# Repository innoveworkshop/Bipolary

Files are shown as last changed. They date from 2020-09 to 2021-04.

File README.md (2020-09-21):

# Bipolary

A minimalist discrete desktop class-A headphone amplifier.

## Follow Along

If you want to learn more about this project and also follow along its journey,
check out the [project's YouTube playlist](https://www.youtube.com/playlist?list=PLbjMhZ3Qv6a8xDwKZuQG69gMUy-2NGEBN).

## Component Library

In order to keep my projects 100% consistent I've built my own Eagle library,
which is all standardized and nice. So if you want to hack on this project be
sure to download the [Innove Workshop Eagle library](https://github.com/innoveworkshop/InnoveWorkshop-Eagle-Library).

## License

<br />This work is licensed under a <a rel="license" href="http://creativecommons.org/licenses/by-nc-sa/4.0/">Creative Commons Attribution-NonCommercial-ShareAlike 4.0 International License</a>.

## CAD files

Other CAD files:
CAD/Top Plate.dwg
CAD/Enclosure.dwg
CAD/Base Plate.dwg
CAD/Side Plates.dwg

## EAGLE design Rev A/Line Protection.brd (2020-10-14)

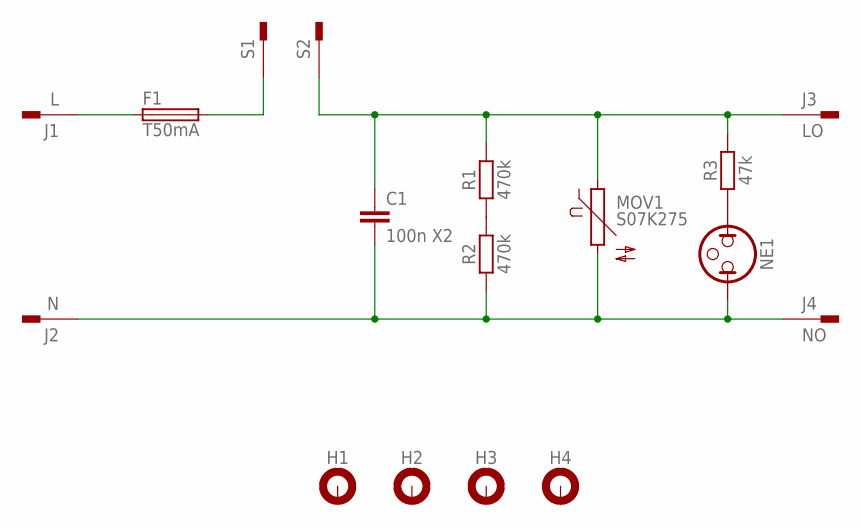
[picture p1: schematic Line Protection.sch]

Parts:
C1: 100n X2; C150-054X183
F1: T50mA; CFH14
H1, H2, H3, H4: MOUNT-PAD-ROUND3.0; 3,0-PAD
J1: L; F061.100
J2: N; F061.100
J3: LO; F061.100
J4: NO; F061.100
MOV1: S07K275
NE1: NEON-T2
R1, R2: 470k; 0207/10
R3: 47k; 0207/10
S1, S2: FASTON-250D140; F061.100

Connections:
unnamed: F1.1, J1.A1, J1.A2
unnamed: R1.1, R2.2
unnamed: NE1.1, R3.1
unnamed: F1.2, S1.A1, S1.A2
NEUTRAL: C1.2, J2.A1, J2.A2, J4.A1, J4.A2, MOV1.2, NE1.2, R2.1
SLIVE: C1.1, J3.A1, J3.A2, MOV1.1, R1.2, R3.2, S2.A1, S2.A2

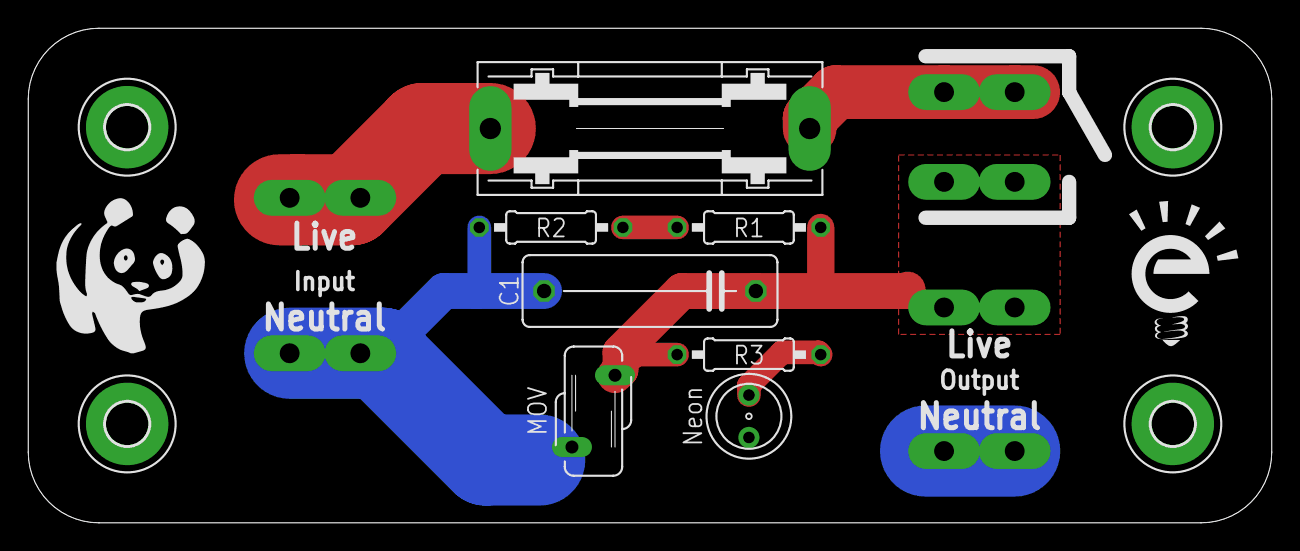
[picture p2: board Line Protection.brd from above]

Board: 2 copper layers, 88.0 x 35.0 mm, 17 parts (0 on the bottom side), 6 nets.

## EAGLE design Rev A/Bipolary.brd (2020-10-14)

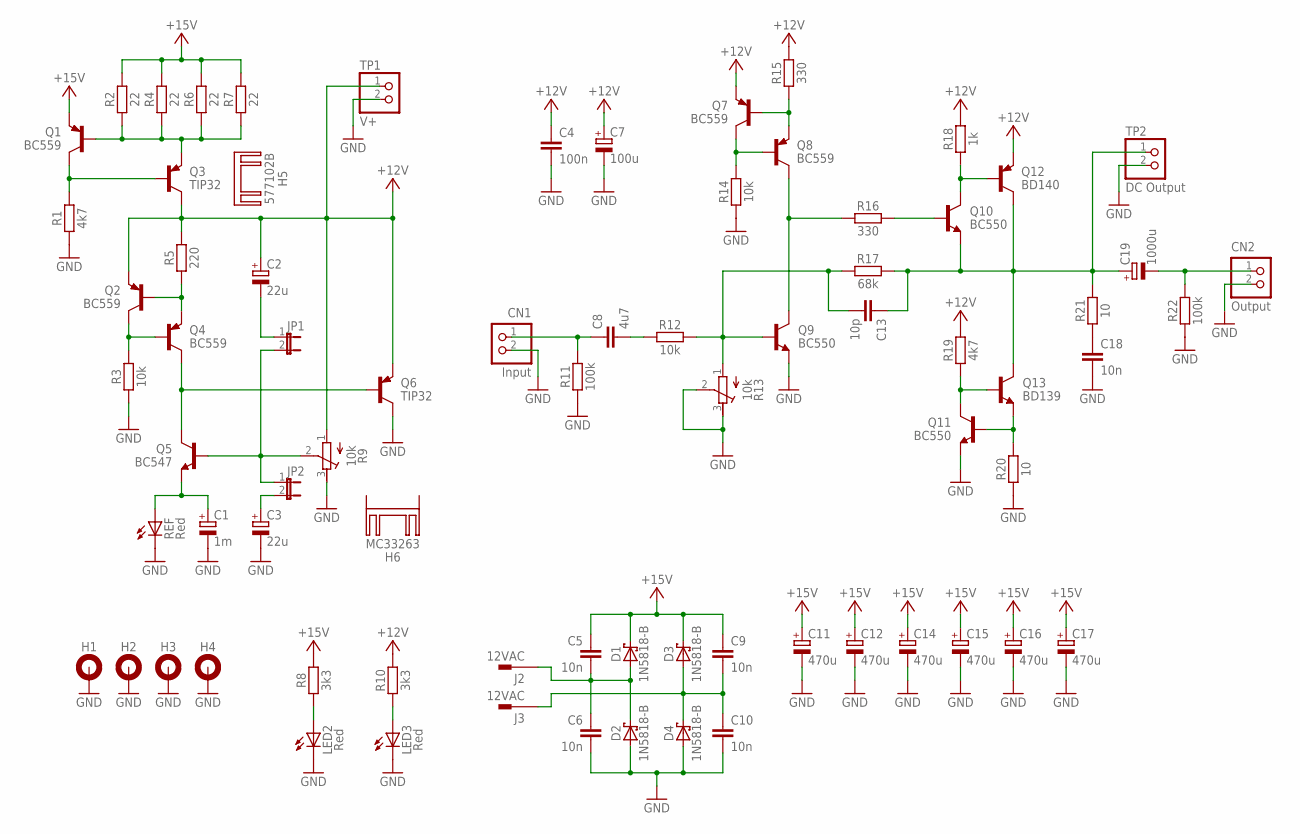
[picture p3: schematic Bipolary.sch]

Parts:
C1: 1m; E3,5-8
C2, C3: 22u; E2-5
C4: 100n; C050-025X075
C5, C6, C9, C10, C18: 10n; C050-025X075
C7: 100u; E3,5-8
C8: 4u7; C150-084X183
C11, C12, C14, C15, C16, C17: 470u; E5-10
C13: 10p; C050-025X075
C19: 1000u; E5-10
CN1: Input; B2B-XH-A
CN2: Output; B2B-XH-A
D1, D2, D3, D4: 1N5818-B; DO41-7.6
H1, H2, H3, H4: MOUNT-PAD-ROUND3.0; 3,0-PAD
H5: 577102B; D02S
H6: MC33263; SK104-PAD
J2, J3: 12VAC; F061.100
JP1, JP2: JP1E; JP1
LED2, LED3: Red; LED5MM
Q1, Q2, Q4, Q7, Q8: BC559; TO92
Q3, Q6: TIP32; TO220V
Q5: BC547; TO92
Q9, Q10, Q11: BC550; TO92
Q12: BD140; TO126V
Q13: BD139; TO126V
R1, R19: 4k7; 0207/10
R2, R4, R6, R7: 22; 0207/10
R3, R12, R14: 10k; 0207/10
R5: 220; 0207/10
R8, R10: 3k3; 0207/10
R9, R13: 10k; RTRIM3296Y
R11, R22: 100k; 0207/10
R15, R16: 330; 0207/10
R17: 68k; 0207/10
R18: 1k; 0207/10
R20, R21: 10; 0207/10
REF: Red; LED5MM
TP1: V+; 1X02
TP2: DC Output; 1X02

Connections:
+12V: C2.+, C4.1, C7.+, Q2.3 (E), Q3.2 (C), Q6.3 (E), Q7.3 (E), Q12.1 (E), R5.2, R9.1 (A), R10.2, R15.2, R18.2, R19.2, TP1.1
+15V: C5.1, C9.1, C11.+, C12.+, C14.+, C15.+, C16.+, C17.+, D1.C, D3.C, Q1.3 (E), R2.2, R4.2, R6.2, R7.2, R8.2
DCOUTPUT: C13.1, C19.+, Q10.3 (E), Q12.2 (C), Q13.2 (C), R17.2, R21.2, TP2.1
GND: C1.-, C3.-, C4.2, C6.2, C7.-, C10.2, C11.-, C12.-, C14.-, C15.-, C16.-, C17.-, C18.2, CN1.2, CN2.2, D2.A, D4.A, H1.B3,0, H2.B3,0, H3.B3,0, H4.B3,0, LED2.K (C), LED3.K (C), Q6.2 (C), Q9.3 (E), Q11.3 (E), R1.1, R3.1, R9.3 (E), R11.1, R13.2 (S), R13.3 (E), R14.1, R20.1, R22.1, REF.K (C), TP1.2, TP2.2
INPUT: C8.1, CN1.1, R11.2
INTSTAGE: Q8.1 (C), Q9.1 (C), R16.1
unnamed: Q1.1 (C), Q3.1 (B), R1.2
unnamed: C8.2, R12.1
unnamed: C5.2, C6.1, D1.A, D2.C, J2.A1, J2.A2
unnamed: Q7.1 (C), Q8.2 (B), R14.2
unnamed: Q7.2 (B), Q8.3 (E), R15.1
unnamed: Q10.1 (C), Q12.3 (B), R18.1
unnamed: Q10.2 (B), R16.2
unnamed: Q11.1 (C), Q13.3 (B), R19.1
unnamed: Q11.2 (B), Q13.1 (E), R20.2
unnamed: C18.1, R21.1
unnamed: Q1.2 (B), Q3.3 (E), R2.1, R4.1, R6.1, R7.1
unnamed: Q2.2 (B), Q4.3 (E), R5.1
unnamed: Q2.1 (C), Q4.2 (B), R3.2
unnamed: Q4.1 (C), Q5.1 (C), Q6.1 (B)
unnamed: C1.+, Q5.3 (E), REF.A
unnamed: JP1.2, JP2.1, Q5.2 (B), R9.2 (S)
unnamed: C2.-, JP1.1
unnamed: C3.+, JP2.2
unnamed: C9.2, C10.1, D3.A, D4.C, J3.A1, J3.A2
unnamed: LED3.A, R10.1
unnamed: LED2.A, R8.1
NFB: C13.2, Q9.2 (B), R12.2, R13.1 (A), R17.1
OUTPUT: C19.-, CN2.1, R22.2

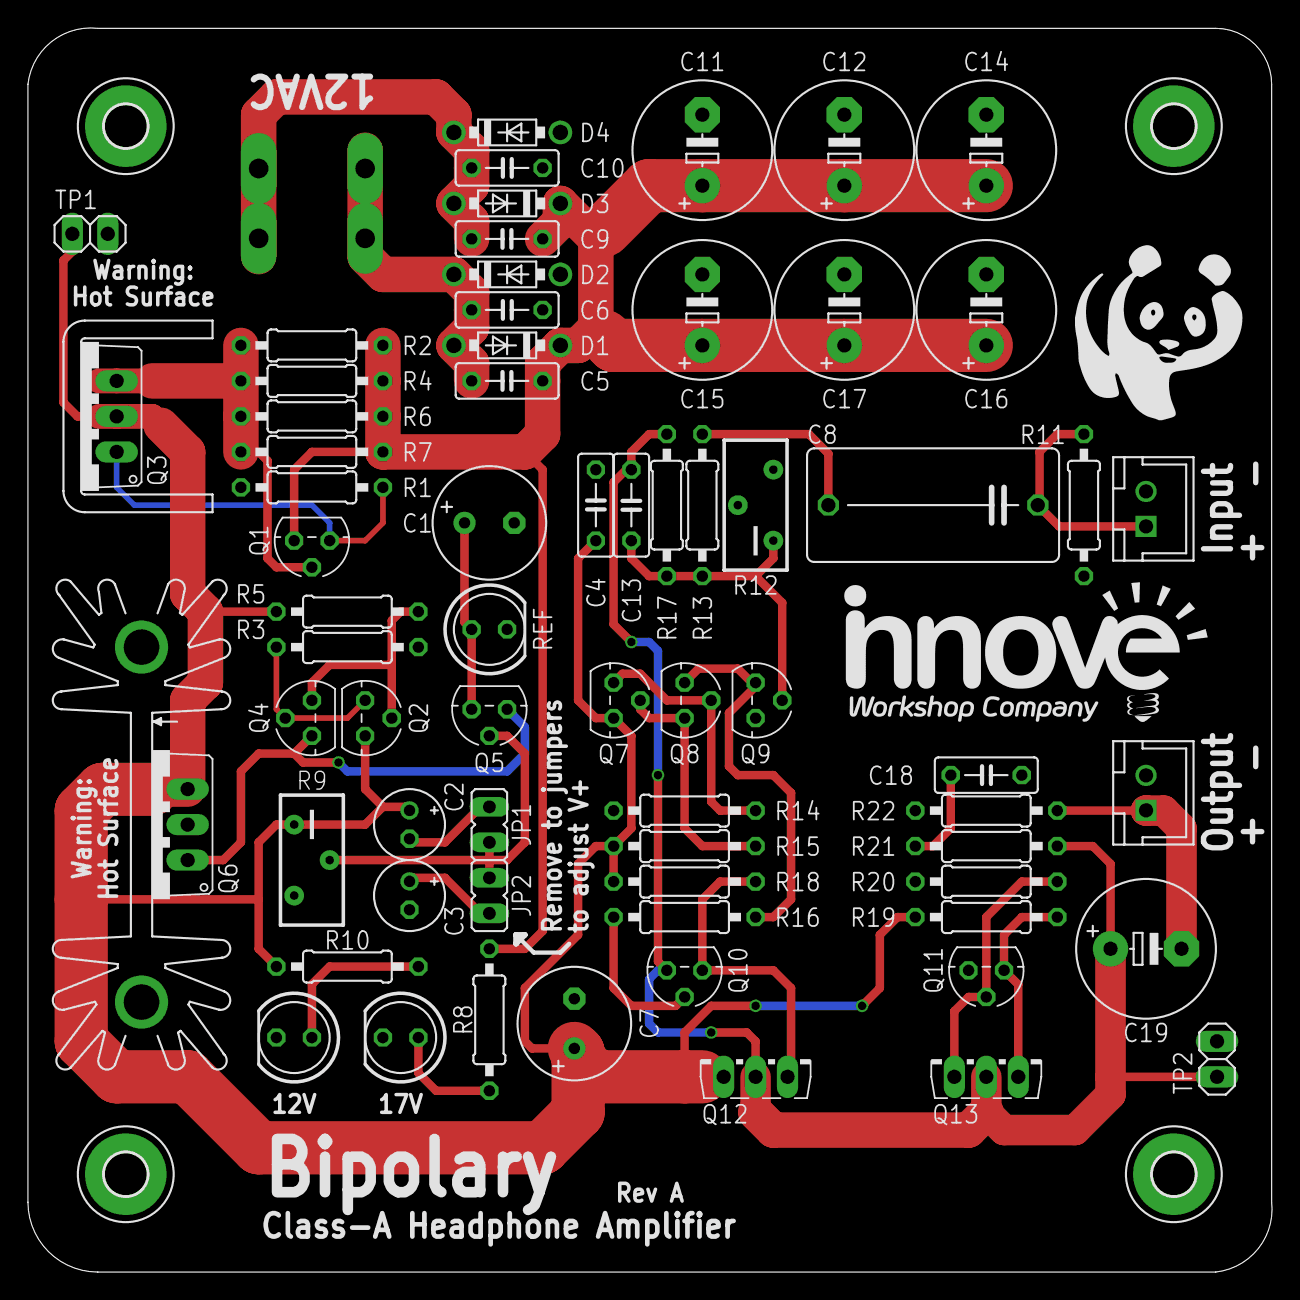
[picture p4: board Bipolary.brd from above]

Board: 2 copper layers, 89.0 x 89.0 mm, 75 parts (0 on the bottom side), 29 nets.

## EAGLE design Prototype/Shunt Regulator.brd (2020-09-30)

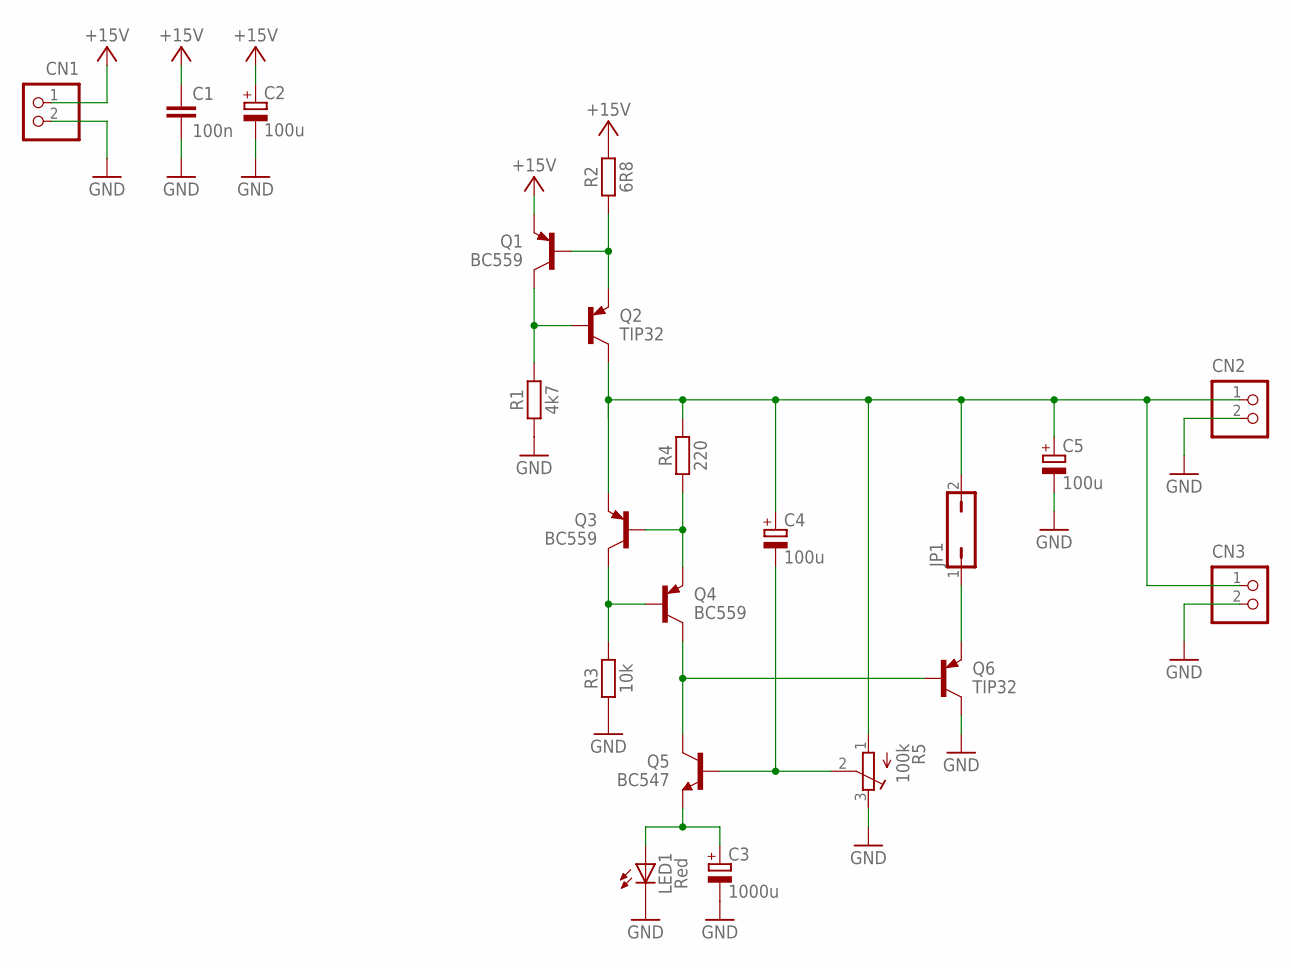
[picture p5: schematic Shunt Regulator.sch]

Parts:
C1: 100n; C050-025X075
C2, C4, C5: 100u; E2,5-6
C3: 1000u; E5-10
CN1, CN2, CN3: B2B-XH-A
JP1: JP1Q; JP1
LED1: Red; LED5MM
Q1, Q3, Q4: BC559; TO92
Q2, Q6: TIP32; TO220V
Q5: BC547; TO92
R1: 4k7; 0207/10
R2: 6R8; 0207/10
R3: 10k; 0207/10
R4: 220; 0207/10
R5: 100k; RTRIM3296Y

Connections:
+15V: C1.1, C2.+, CN1.1, Q1.3 (E), R2.2
GND: C1.2, C2.-, C3.-, C5.-, CN1.2, CN2.2, CN3.2, LED1.K (C), Q6.2 (C), R1.1, R3.1, R5.3 (E)
unnamed: Q1.1 (C), Q2.1 (B), R1.2
unnamed: Q1.2 (B), Q2.3 (E), R2.1
unnamed: Q4.1 (C), Q5.1 (C), Q6.1 (B)
unnamed: Q3.2 (B), Q4.3 (E), R4.1
unnamed: Q3.1 (C), Q4.2 (B), R3.2
unnamed: C3.+, LED1.A, Q5.3 (E)
unnamed: C4.-, Q5.2 (B), R5.2 (S)
unnamed: JP1.1, Q6.3 (E)
OUTPUT: C4.+, C5.+, CN2.1, CN3.1, JP1.2, Q2.2 (C), Q3.3 (E), R4.2, R5.1 (A)

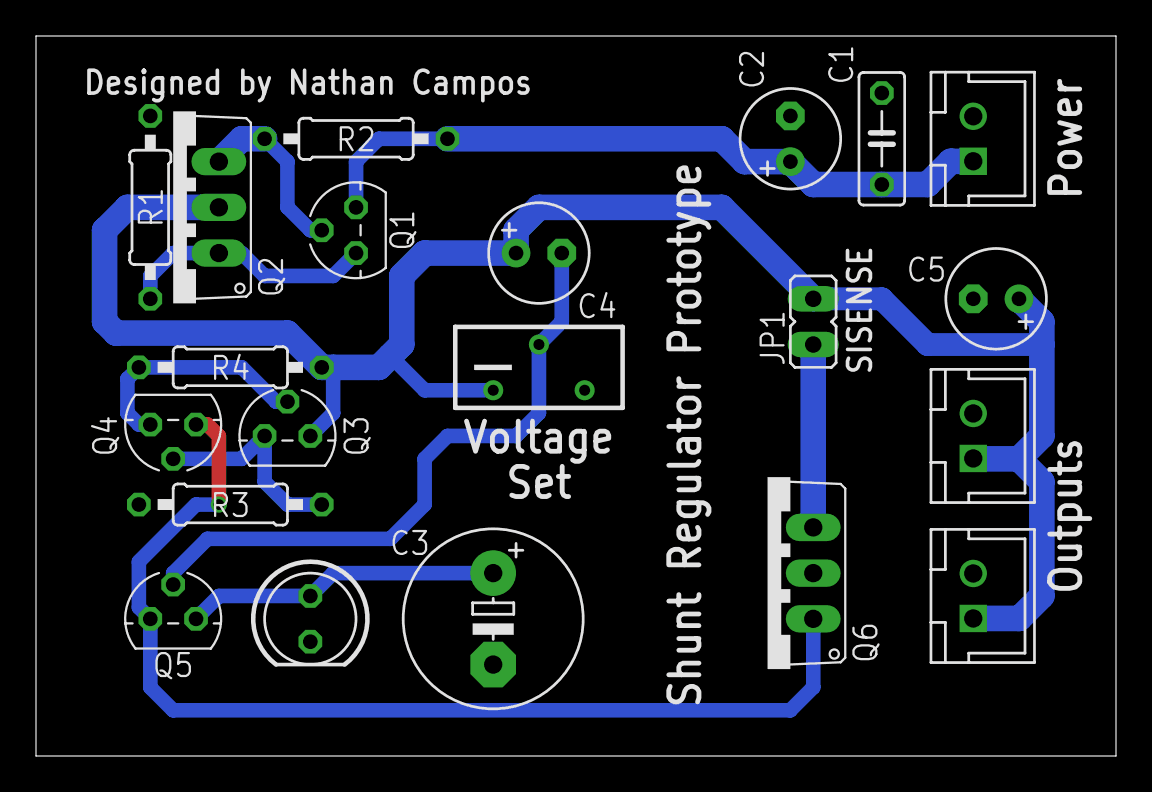
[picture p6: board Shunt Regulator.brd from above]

Board: 2 copper layers, 60.0 x 40.0 mm, 21 parts (0 on the bottom side), 11 nets.

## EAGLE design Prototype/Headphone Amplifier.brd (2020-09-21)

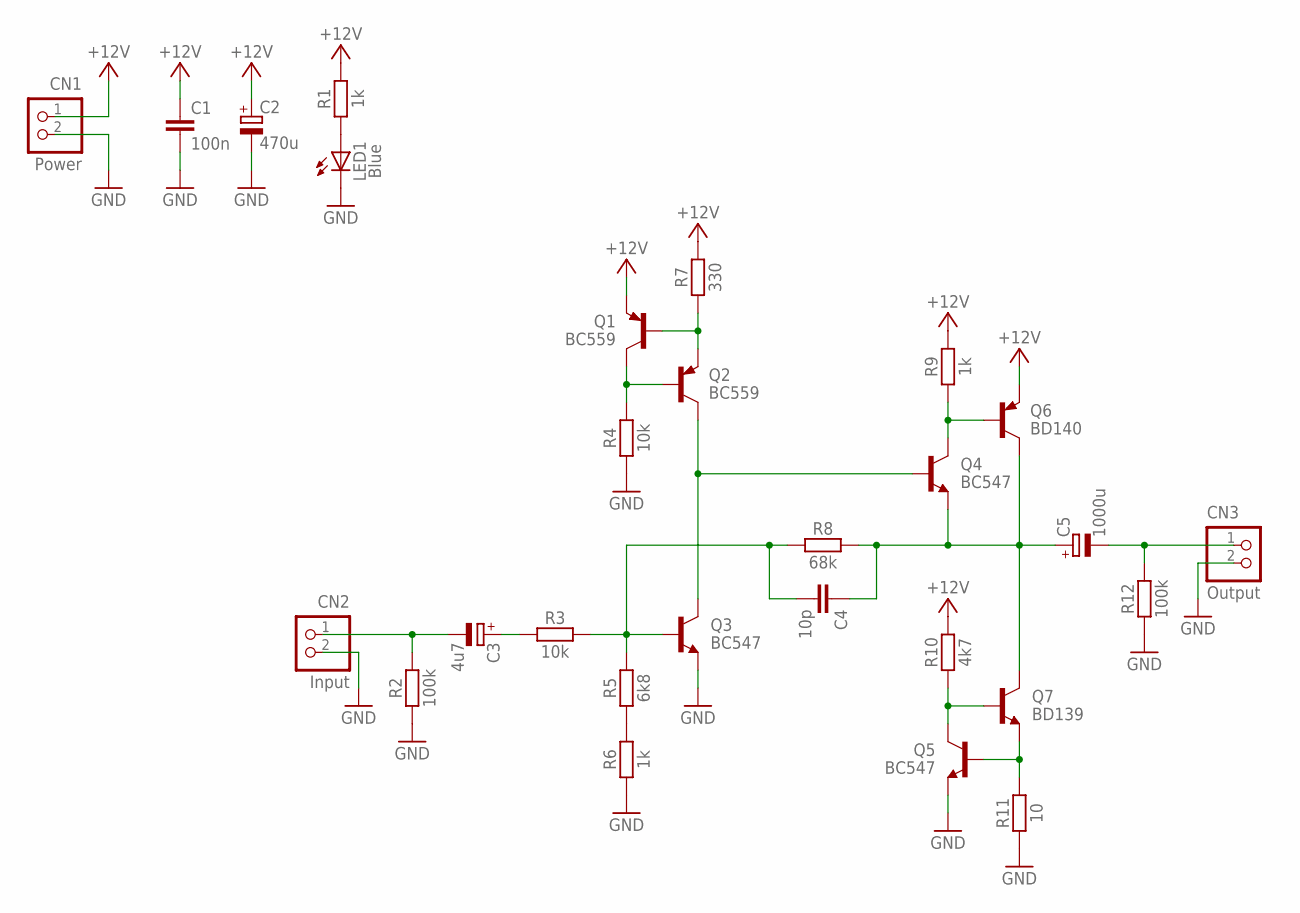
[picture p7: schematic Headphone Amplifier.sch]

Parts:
C1: 100n; C050-025X075
C2: 470u; E5-10
C3: 4u7; E1,8-4
C4: 10p; C050-025X075
C5: 1000u; E5-10
CN1: Power; B2B-XH-A
CN2: Input; B2B-XH-A
CN3: Output; B2B-XH-A
LED1: Blue; LED5MM
Q1, Q2: BC559; TO92
Q3, Q4, Q5: BC547; TO92
Q6: BD140; TO126V
Q7: BD139; TO126V
R1, R6, R9: 1k; 0207/10
R2, R12: 100k; 0207/10
R3, R4: 10k; 0207/10
R5: 6k8; 0207/10
R7: 330; 0207/10
R8: 68k; 0207/10
R10: 4k7; 0207/10
R11: 10; 0207/10

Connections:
+12V: C1.1, C2.+, CN1.1, Q1.3 (E), Q6.1 (E), R1.2, R7.2, R9.2, R10.2
DCOUTPUT: C4.1, C5.+, Q4.3 (E), Q6.2 (C), Q7.2 (C), R8.2
GND: C1.2, C2.-, CN1.2, CN2.2, CN3.2, LED1.K (C), Q3.3 (E), Q5.3 (E), R2.1, R4.1, R6.1, R11.1, R12.1
INPUT: C3.-, CN2.1, R2.2
INTSTAGE: Q2.1 (C), Q3.1 (C), Q4.2 (B)
unnamed: R5.1, R6.2
unnamed: C3.+, R3.1
unnamed: LED1.A, R1.1
unnamed: Q1.1 (C), Q2.2 (B), R4.2
unnamed: Q1.2 (B), Q2.3 (E), R7.1
unnamed: Q4.1 (C), Q6.3 (B), R9.1
unnamed: Q5.1 (C), Q7.3 (B), R10.1
unnamed: Q5.2 (B), Q7.1 (E), R11.2
NFB: C4.2, Q3.2 (B), R3.2, R5.2, R8.1
OUTPUT: C5.-, CN3.1, R12.2

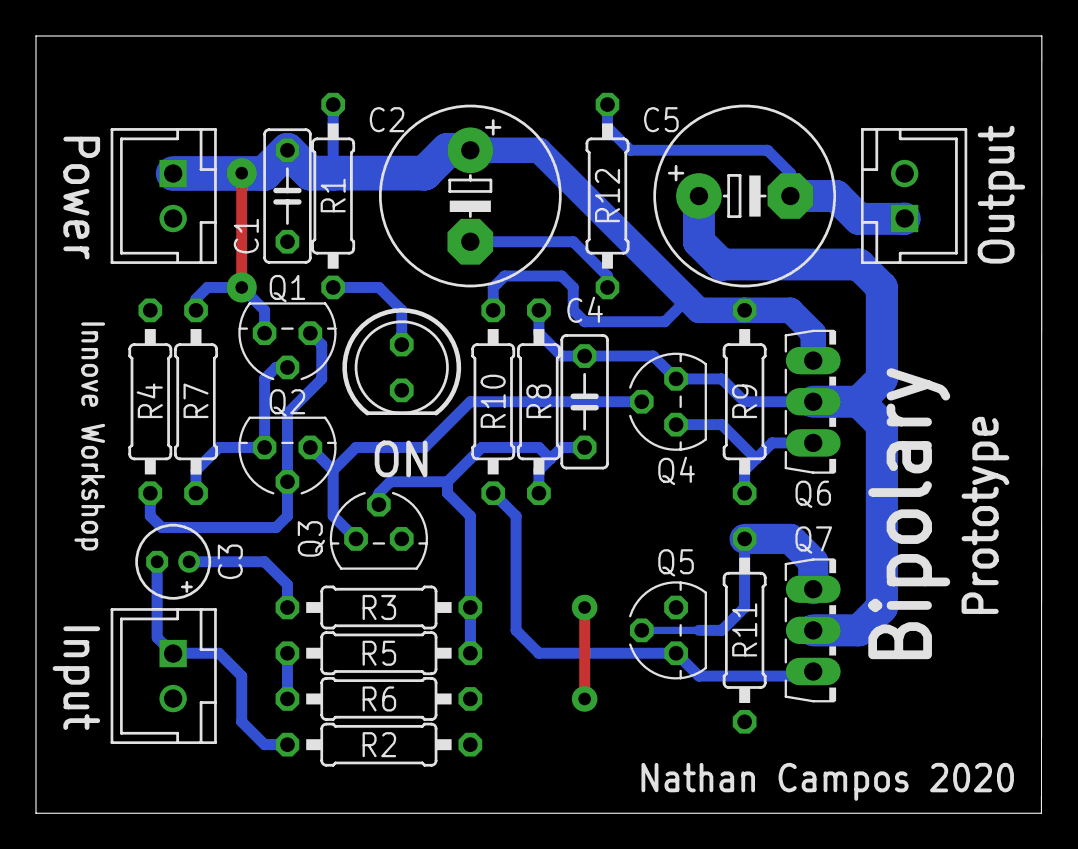
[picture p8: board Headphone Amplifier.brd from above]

Board: 2 copper layers, 55.9 x 43.2 mm, 28 parts (0 on the bottom side), 15 nets.

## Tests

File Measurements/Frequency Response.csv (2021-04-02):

Frequency | Unloaded | 30 Ohms | 150 Ohms
1 | 1.800 | 0.140 | 0.880
2 | 4.140 | 0.576 | 3.100
3 | 5.720 | 1.100 | 4.960
4 | 6.760 | 1.580 | 6.160
5 | 7.400 | 2.000 | 6.920
6 | 7.800 | 2.300 | 7.480
7 | 8.160 | 2.500 | 7.770
8 | 8.400 | 2.670 | 8.160
9 | 8.520 | 2.800 | 8.320
10 | 8.700 | 2.890 | 8.480
20 | 9.040 | 3.290 | 9.000
30 | 9.100 | 3.360 | 9.040
40 | 9.200 | 3.400 | 9.040
50 | 9.200 | 3.430 | 9.100
60 | 9.200 | 3.450 | 9.180
70 | 9.280 | 3.470 | 9.200
80 | 9.320 | 3.500 | 9.250
90 | 9.360 | 3.500 | 9.300
100 | 9.360 | 3.510 | 9.360
200 | 9.360 | 3.510 | 9.280
300 | 9.360 | 3.510 | 9.200
400 | 9.280 | 3.510 | 9.200
500 | 9.280 | 3.510 | 9.200
600 | 9.280 | 3.510 | 9.200
700 | 9.280 | 3.510 | 9.200
800 | 9.280 | 3.510 | 9.200
900 | 9.280 | 3.510 | 9.200
1000 | 9.280 | 3.510 | 9.200
2000 | 9.280 | 3.510 | 9.200
3000 | 9.280 | 3.510 | 9.200
4000 | 9.280 | 3.480 | 9.200
5000 | 9.280 | 3.480 | 9.200
6000 | 9.280 | 3.480 | 9.200
7000 | 9.280 | 3.480 | 9.200
8000 | 9.280 | 3.480 | 9.200
9000 | 9.280 | 3.480 | 9.200
10000 | 9.280 | 3.480 | 9.200
15000 | 9.280 | 3.480 | 9.200
20000 | 9.280 | 3.450 | 9.200
30000 | 9.200 | 3.430 | 9.100
40000 | 9.040 | 3.390 | 9.040
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

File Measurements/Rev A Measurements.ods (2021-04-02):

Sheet: Frequency_Response
Frequency | Output Unloaded (Vpp) | Output 30 Ohms (Vpp) | Output 150 Ohms (Vpp) |  | Frequency Response
1 | 1.800 | 0.140 | 0.880 |  | Result | Minimum (Vpp) | Maximum (Vpp)
2 | 4.140 | 0.576 | 3.100 | Unloaded | -0.302 | 9.040 | 9.360
3 | 5.720 | 1.100 | 4.960 | 30 Ohms | -0.379 | 3.360 | 3.510
4 | 6.760 | 1.580 | 6.160 | 150 Ohms | -0.302 | 9.040 | 9.360
5 | 7.400 | 2.000 | 6.920
6 | 7.800 | 2.300 | 7.480
7 | 8.160 | 2.500 | 7.770
8 | 8.400 | 2.670 | 8.160
9 | 8.520 | 2.800 | 8.320
10 | 8.700 | 2.890 | 8.480
20 | 9.040 | 3.290 | 9.000
30 | 9.100 | 3.360 | 9.040
40 | 9.200 | 3.400 | 9.040
50 | 9.200 | 3.430 | 9.100
60 | 9.200 | 3.450 | 9.180
70 | 9.280 | 3.470 | 9.200
80 | 9.320 | 3.500 | 9.250
90 | 9.360 | 3.500 | 9.300
100 | 9.360 | 3.510 | 9.360
200 | 9.360 | 3.510 | 9.280
300 | 9.360 | 3.510 | 9.200
400 | 9.280 | 3.510 | 9.200
500 | 9.280 | 3.510 | 9.200
600 | 9.280 | 3.510 | 9.200
700 | 9.280 | 3.510 | 9.200
800 | 9.280 | 3.510 | 9.200
900 | 9.280 | 3.510 | 9.200
1000 | 9.280 | 3.510 | 9.200
2000 | 9.280 | 3.510 | 9.200
3000 | 9.280 | 3.510 | 9.200
4000 | 9.280 | 3.480 | 9.200
5000 | 9.280 | 3.480 | 9.200
6000 | 9.280 | 3.480 | 9.200
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

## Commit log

2020-09-20 Added EAGLE files
    [Headphone Amplifier.sch]
2020-09-20 Renumbered the reference designators in the schematic
    [Headphone Amplifier.sch]
2020-09-21 Prototype circuit done
    [Headphone Amplifier.brd, Headphone Amplifier.sch]
2020-09-29 Mitigating oscillations
    [Headphone Amplifier (Fixed).sch]
2020-09-29 Started working on the shunt regulator
    [Shunt Regulator.sch]
2020-09-30 Doing some stability simulations on the regulator
2020-09-30 Finished the shunt regulator prototype
    [Shunt Regulator.brd, Shunt Regulator.sch]
2020-10-14 Added Rev A schematic and board layout
    [Bipolary.brd, Bipolary.sch]
2020-10-14 Minor tweaks
    [Bipolary.brd, Bipolary.sch]
2020-10-14 Finished the line protection schematic and board layout
    [Line Protection.brd, Line Protection.sch]
2020-11-30 Started a blank AutoCAD drawing for the enclosure
    [Enclosure.dwg]
2020-11-30 Determined the relative position of the transformer and boards
    [Enclosure.dwg]
2020-11-30 CAD - Placed spacers and positioned everything vertically
    [Enclosure.dwg]
2020-12-01 CAD - Positioned the boards in their final location and placed the sheet metal base, front and back
    [Enclosure.dwg]
2020-12-01 CAD - Finalized the size of the enclosure after some paper fitting
    [Enclosure.dwg]
2020-12-01 CAD - Added the front panel holes and added the switch and neon indicator
    [Enclosure.dwg]
2020-12-01 CAD - Made all the holes for screws in the sheet metal base
    [Enclosure.dwg]
2020-12-01 CAD - Added the 1/4 inch jack to the front panel
    [Enclosure.dwg]
2020-12-02 CAD - Finished placing all the back panel components
    [Enclosure.dwg]
2020-12-02 CAD - Added the back RCA input jacks I forgot
    [Enclosure.dwg]
2020-12-02 CAD - Finished the 3D model of the bottom plate
    [Enclosure.dwg]
2020-12-02 CAD - Laid out a flat pattern
    [Enclosure.dwg, Flat Pattern.dwg]
2020-12-03 CAD - Finished the base flat pattern
    [Flat Pattern.dwg]
2020-12-03 CAD - Added side faces to the 3D model
    [Enclosure.dwg]
2020-12-03 CAD - Renamed the base plate flat pattern drawing
    [Base Plate Flat Pattern.dwg, Flat Pattern.dwg]
2020-12-03 CAD - Added the flat pattern for the side plates
    [Side Plates Flat Pattern.dwg]
2020-12-03 CAD - Added the top plate to the 3D model
    [Enclosure.dwg]
2020-12-03 CAD - Just making sure the side plate flat pattern was saved using the R14 format
    [Side Plates Flat Pattern.dwg]
2020-12-03 CAD - Finished the top plate flat pattern
    [Top Plate Flat Pattern.dwg]
2020-12-21 Fixed something on the side plates flat pattern. Can't remember
    [Side Plates Flat Pattern.dwg]
2020-12-21 Updated all the CAD drawings with layouts for printing
    [Base Plate Flat Pattern.dwg, Base Plate.dwg, Enclosure.dwg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]
2021-04-02 Added some measurements from the final project
    [Frequency Response.csv, Output Levels.csv, Rev A Measurements.ods]
2021-04-02 Removed the output level graph
    [Output Levels.csv]
